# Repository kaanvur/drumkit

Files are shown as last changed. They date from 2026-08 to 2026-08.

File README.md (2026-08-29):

# ESP32-C3 Bluetooth MIDI Drum Kit

> 3D Printer ile basılmış, BLE MIDI ile kablosuz çalışan DIY elektronik davul seti.

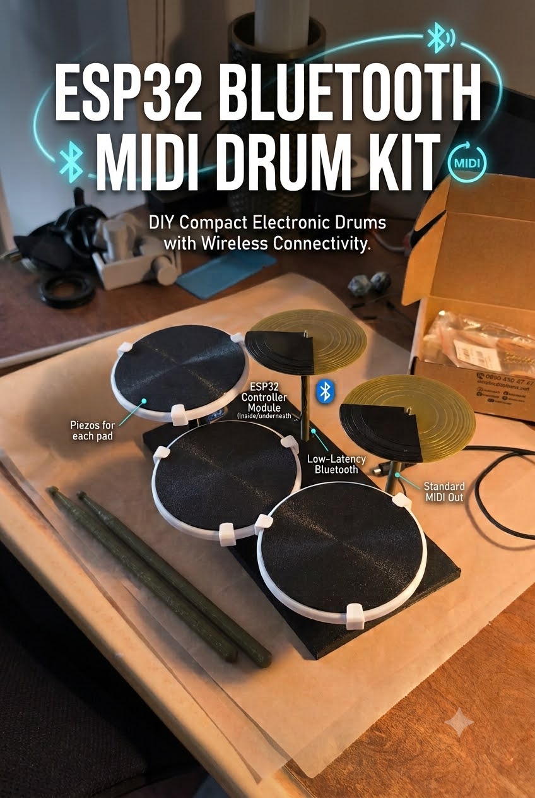
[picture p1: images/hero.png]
Hero


[**MakerWorld'de Görüntüle**](https://makerworld.com/tr/models/3235210-drum-kit-using-esp32-bluetooth-midi)

## 🇹🇷 Türkçe

### Proje Hakkında

Bu proje, **ESP32-C3 Super Mini** mikrodenetleyicisi kullanılarak oluşturulmuş компакт bir elektronik davul setidir. 3D printer ile basılmış pad'ler, piezo sensörler ve Bluetooth Low Energy (BLE) MIDI bağlantısı ile çalışır.

### Ozellikler

- **5 Pad**: Kick, Snare, Hi-Hat, Tom, Crash Cymbal
- **BLE MIDI**: Kablosuz Bluetooth bağlantısı (düşük gecikme)
- **Velocity Sensitivity**: Vuruş şiddetine göre MIDI velocity
- **3D Baskı**: Tamamı 3D printer ile basılabilir gövde
- **Kompakt**: Masaüstü boyutunda, taşınabilir tasarım

### Önemli: Analog Pin Gerekliliği

Piezo sensörler **analog pinlere** bağlanır. Her piezo için bir analog pin gereklidir.

| Mikrodenetleyici | Analog Pin Sayısı | Maks. Pad |
|---|---|---|
| ESP32-C3 Super Mini | 5 (GPIO0-4) | 5 pad |
| ESP32-WROOM-32D | 18 (GPIO32-39, GPIO0-5, GPIO34-39) | 18 pad |
| ESP32-S3 Super Mini | 20 | 20 pad |
| Arduino Uno | 6 (A0-A5) | 6 pad |
| Arduino Nano | 8 (A0-A7) | 8 pad |

> **Daha fazla pad istiyorsanız**: ESP32-WROOM-32D veya ESP32-S3 gibi daha çok analog pin'e sahip kartlar kullanarak 10-15 pad'li更大的鼓组 kurabilirsiniz. Kodda `NUM_PADS` sabitini ve `piezoPins` dizisini değiştirmeniz yeterlidir.

### Gerekli Malzemeler

| Bileşen | Adet | Not |
|---|---|-----|
| ESP32-C3 Super Mini | 1 | USB-C girişli, dahili LED (GPIO8) |
| Piezo Sensör (27mm) | 5 | Her pad için bir adet |
| Direnç (1MΩ) | 5 | Pull-down direnç |
| Jumper Kablo | ~20 | Erkek-dişi |
| USB-C Kablo | 1 | Kod yükleme için |

### 3D Baskı Parçaları

[`drumkit.3mf`](3d-models/drumkit.3mf) dosyası 6 baskı plakası içerir:

| Plaka | Renk | İçerik |
|---|---|---|
| 01 | Beyaz | Pad çerçeveleri + klipsler |
| 02 | Siyah | Pad üst yüzeyleri (3 yuvarlak + 2 zil) |
| 03 | Siyah | Zil ayakları / tutucular |
| 04 | Yeşil | Zil üst yüzeyleri + klipsler |
| 05 | Siyah | Ana gövde (base plate) |
| 06 | Yeşil | Davul çubukları |

**Önerilen malzeme**: PLA veya PLA+ ( PETG de olur )

### Bağlantı Şeması

```
ESP32-C3 Super Mini
┌─────────────────┐
│                 │
│  GPIO0 ──────────── Piezo 1 (Kick)    + 1MΩ direnç
│  GPIO1 ──────────── Piezo 2 (Snare)   + 1MΩ direnç
│  GPIO2 ──────────── Piezo 3 (Hi-Hat)  + 1MΩ direnç
│  GPIO3 ──────────── Piezo 4 (Tom)     + 1MΩ direnç
│  GPIO4 ──────────── Piezo 5 (Cymbal)  + 1MΩ direnç
│                 │
│  GND ────────────── Piezo (-)         │
│                 │
│  USB-C ──────── Kod yükleme           │
└─────────────────┘

Not: GPIO8 - Dahili LED (devreye ekstra LED baglantisi gerekmez)
```

Detaylı bağlantı için: [docs/WIRING.md](docs/WIRING.md)

### Montaj

1. 3D parçaları bas
2. Piezo sensörleri pad'lere yapıştır
3. Kablo lehimleme / bağlama
4. ESP32'yi gövdeye yerleştir
5. Kodu yükle
6. Bluetooth ile bağlan

Detaylı montaj için: [docs/ASSEMBLY.md](docs/ASSEMBLY.md)

### Kod Yükleme

Arduino IDE ile:
1. ESP32 board paketini yükle
2. `firmware/drumkit/drumkit.ino` dosyasını aç
3. Board: "ESP32C3 Dev Module" seç
4. Upload

Detaylı yükleme için: [docs/FLASHING.md](docs/FLASHING.md)

### Bluetooth MIDI Kullanma

Cihaz adı: **ESP32-C3-Drum**

| Platform | Uygulama | Durum |
|---|---|---|
| macOS | GarageBand | ✅ Doğrudan çalışır |
| macOS | Logic Pro | ✅ Doğrudan çalışır |
| iOS | GarageBand | ✅ Doğrudan çalışır |
| iOS | Cubasis 3 | ✅ Doğrudan çalışır |
| Android | n-track Studio | ✅ Doğrudan çalışır |
| Android | Caustic 3 | ✅ Doğrudan çalışır |
| Web | BandLab | ✅ BLE MIDI destekli |
| Web | Soundtrap | ✅ BLE MIDI destekli |
| Windows | loopMIDI + DAW | ⚠️ BLE-MIDI sürücü gerekli |

> **Not**: ESP32-C3 dahili LED (GPIO8) kullanır. Devreye ekstra LED bağlamanıza gerek yoktur.

Detaylı bağlantı ve uygulama kılavuzları için: [docs/BLUETOOTH.md](docs/BLUETOOTH.md)

---

## 🇬🇧 English

### About

A compact DIY electronic drum kit built with an **ESP32-C3 Super Mini** microcontroller. Features 3D-printed pads, piezo sensors, and wireless Bluetooth Low Energy (BLE) MIDI connectivity.

[**View on MakerWorld**](https://makerworld.com/tr/models/3235210-drum-kit-using-esp32-bluetooth-midi)

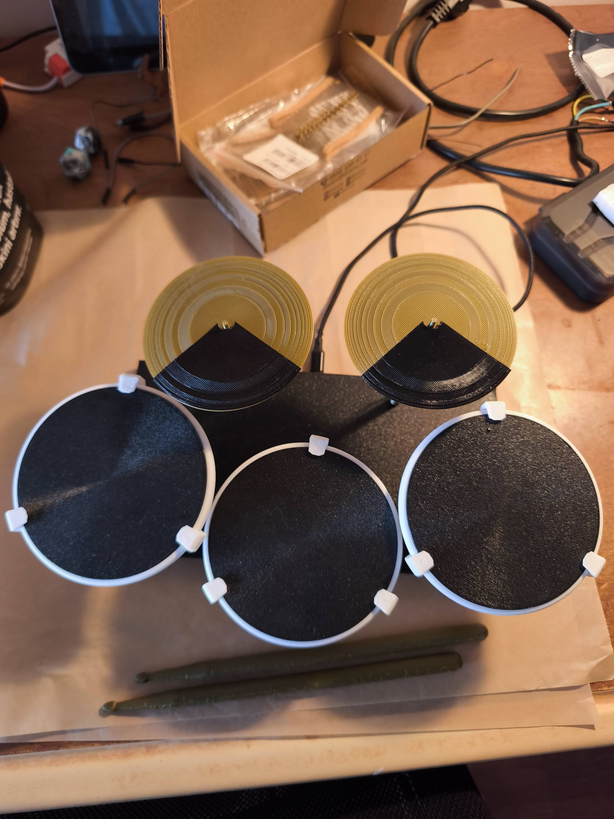
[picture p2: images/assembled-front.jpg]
Assembled


### Features

- **5 Pads**: Kick, Snare, Hi-Hat, Tom, Crash Cymbal
- **BLE MIDI**: Wireless Bluetooth connection (low latency)
- **Velocity Sensitivity**: MIDI velocity based on hit strength
- **3D Printed**: Fully printable body and pads
- **Compact**: Desktop-sized, portable design

### Important: Analog Pin Requirement

Piezo sensors connect to **analog pins**. Each piezo requires one analog pin.

| Microcontroller | Analog Pin Count | Max Pads |
|---|---|---|
| ESP32-C3 Super Mini | 5 (GPIO0-4) | 5 pads |
| ESP32-WROOM-32D | 18 (GPIO32-39, GPIO0-5, GPIO34-39) | 18 pads |
| ESP32-S3 Super Mini | 20 | 20 pads |
| Arduino Uno | 6 (A0-A5) | 6 pads |
| Arduino Nano | 8 (A0-A7) | 8 pads |

> **Need more pads?**: Use microcontrollers with more analog pins like ESP32-WROOM-32D or ESP32-S3 to build larger drum kits with 10-15 pads. Just change the `NUM_PADS` constant and `piezoPins` array in the code.

### Required Components

| Component | Qty | Note |
|---|-----|---|
| ESP32-C3 Super Mini | 1 | USB-C port, built-in LED (GPIO8) |
| Piezo Sensor (27mm) | 5 | One per pad |
| Resistor (1MΩ) | 5 | Pull-down resistor |
| Jumper Wires | ~20 | Male-to-female |
| USB-C Cable | 1 | For flashing |

### 3D Printed Parts

[`drumkit.3mf`](3d-models/drumkit.3mf) contains 6 build plates:

| Plate | Color | Contents |
|---|---|---|
| 01 | White | Pad frames + clips |
| 02 | Black | Pad top surfaces (3 round + 2 cymbal) |
| 03 | Black | Cymbal stands / holders |
| 04 | Green | Cymbal top surfaces + clips |
| 05 | Black | Main base plate |
| 06 | Green | Drumsticks |

**Recommended material**: PLA or PLA+ (PETG works too)

### Wiring Diagram

```
ESP32-C3 Super Mini
┌─────────────────┐
│                 │
│  GPIO0 ──────────── Piezo 1 (Kick)    + 1MΩ resistor
│  GPIO1 ──────────── Piezo 2 (Snare)   + 1MΩ resistor
│  GPIO2 ──────────── Piezo 3 (Hi-Hat)  + 1MΩ resistor
│  GPIO3 ──────────── Piezo 4 (Tom)     + 1MΩ resistor
│  GPIO4 ──────────── Piezo 5 (Cymbal)  + 1MΩ resistor
│                 │
│  GND ────────────── Piezo (-)         │
│                 │
│  USB-C ──────── Flashing              │
└─────────────────┘

Note: GPIO8 - Built-in LED (no external LED connection needed)
```

For detailed wiring: [docs/WIRING.md](docs/WIRING.md)

### Assembly

1. 3D print all parts
2. Attach piezo sensors to pads
3. Solder / connect wires
4. Mount ESP32 into base
5. Flash the firmware
6. Connect via Bluetooth

For detailed assembly: [docs/ASSEMBLY.md](docs/ASSEMBLY.md)

### Flashing

Using Arduino IDE:
1. Install ESP32 board package
2. Open `firmware/drumkit/drumkit.ino`
3. Select board: "ESP32C3 Dev Module"
4. Upload

For detailed instructions: [docs/FLASHING.md](docs/FLASHING.md)

### Using Bluetooth MIDI

Device name: **ESP32-C3-Drum**

| Platform | App | Status |
|---|-----|---|
| macOS | GarageBand | ✅ Works out of the box |
| macOS | Logic Pro | ✅ Works out of the box |
| iOS | GarageBand | ✅ Works out of the box |
| iOS | Cubasis 3 | ✅ Works out of the box |
| Android | n-track Studio | ✅ Works out of the box |
| Android | Caustic 3 | ✅ Works out of the box |
| Web | BandLab | ✅ BLE MIDI supported |
| Web | Soundtrap | ✅ BLE MIDI supported |
| Windows | loopMIDI + DAW | ⚠️ BLE-MIDI driver needed |

> **Note**: ESP32-C3 uses built-in LED (GPIO8). No external LED connection needed.

For detailed connection and app guides: [docs/BLUETOOTH.md](docs/BLUETOOTH.md)

---

## 📁 Project Structure / Proje Yapısı

```
drumkit/
├── README.md              # This file / Bu dosya
├── LICENSE                # CC BY-NC-SA 4.0
├── firmware/
│   └── drumkit/
│       └── drumkit.ino    # Arduino code / Arduino kodu
├── 3d-models/
│   └── drumkit.3mf        # 3D print file / 3D baskı dosyası
├── docs/
│   ├── WIRING.md          # Wiring guide / Bağlantı rehberi
│   ├── ASSEMBLY.md        # Assembly guide / Montaj rehberi
│   ├── FLASHING.md        # Flashing guide / Kod yükleme rehberi
│   └── BLUETOOTH.md       # Bluetooth MIDI guide / Bluetooth rehberi
└── images/                # Documentation images / Görseller
```

## 📜 License / Lisans

**CC BY-NC-SA 4.0** (Creative Commons Atıf-GayriTicari-AyniLisanslaPaylaş 4.0 Uluslararası)

Bu eser:
- ✅ Kişisel/bireysel kullanım için özgürdür
- ✅ Atıf ile alıntı yapabilirsiniz
- ✅ Değiştirip türetebilirsiniz
- ✗ Ticari amaçla kullanılamaz
- ⚠️ Türev eserler aynı lisansla (CC BY-NC-SA 4.0) paylaşılmalıdır

Detaylı lisans için: [LICENSE](LICENSE)

## � Katkıda Bulunma

Hata bildirimi veya geliştirme önerileriniz için Issue açabilirsiniz.

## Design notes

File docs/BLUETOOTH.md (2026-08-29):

# Bluetooth MIDI Bağlantı Rehberi / Bluetooth MIDI Connection Guide

## 🇹🇷 Türkçe

### Genel Bakış

ESP32-C3 drum kit'iniz **BLE MIDI** (Bluetooth Low Energy MIDI) protokolü ile çalışır. Bu, iOS, macOS ve Android cihazlarla kablosuz olarak MIDI sinyali gönderebilmenizi sağlar.

Cihaz adı: **ESP32-C3-Drum**

> İlk açılışta veya bağlantı koptuğunda ESP32-C3 otomatik olarak reklam (advertising) yapmaya başlar.

---

### macOS (MacBook / iMac) Bağlantısı

#### Adım 1: Bluetooth'u Açın

1. **Sistem Ayarları** (System Settings) > **Bluetooth** menüsüne gidin
2. Bluetooth'u **Açık** konuma getirin
3. "ESP32-C3-Drum" cihazını arama listesinde görün

> Eğer cihaz görünüyorsa, cihaz zaten reklam modundadır. Görünmüyorsa ESP32-C3'ü USB ile besleyin veya RESET butonuna basın.

#### Adım 2: Cihaza Bağlanın

1. "ESP32-C3-Drum" yanındaki **"Bağlan"** (Connect) butonuna tıklayın
2. Bağlantı kurulana kadar bekleyin
3. Bağlantı başarılı olduğunda "Bağlı" (Connected) yazacak

```
Bluetooth Ayarları:
┌─────────────────────────────────────────┐
│  Bulunan Cihazlar:                       │
│                                         │
│  🎵 ESP32-C3-Drum          [Bağlan]     │
│                                         │
└─────────────────────────────────────────┘
```

#### Adım 3: MIDI Studio'da Doğrulama

1. **Araçlar** (Applications) > **Utilites** (Utilities) > **Audio MIDI Kurulumu** (Audio MIDI Setup) uygulamasını açın
2. Üst menüden **Pencere** (Window) > **MIDI Stüdyo** (MIDI Studio) seçin
3. MIDI Studio penceresinde **"ESP32-C3-Drum"** cihazını görmelisiniz
4. Cihaza çift tıklayarak MIDI portlarının aktif olduğunu doğrulayın

> Bu adım zorunlu değildir, ancak bağlantının doğru kurulduğunu doğrulamak için faydalıdır.

#### Adım 4: GarageBand'de Kullanma

1. **GarageBand**'ı açın
2. Yeni bir proje oluşturun veya mevcut bir projeyi açın
3. **Yeni Parça** (New Track) > **Yazılı Enstrüman** (Software Instrument) seçin
4. Sol panelde **Klavye** (Keyboard) veya **Davul Seti** (Drum Kit) enstrümanını seçin

##### MIDI Bağlantısını Ayarlama

1. GarageBand menü çubuğunda **GarageBand > Tercihler** (Preferences) seçin
2. **MIDI** sekmesine gidin
3. **MIDI Giriş** (MIDI Input) bölümünde **"ESP32-C3-Drum"** seçin

```
GarageBand Tercihler:
┌─────────────────────────────────────────┐
│  MIDI                                    │
│                                         │
│  MIDI Giriş: [ ESP32-C3-Drum ▼]         │
│                                         │
│  ✅ MIDI saatini başlat                  │
│  ✅ Sampringleme hızı: 44.1 kHz          │
└─────────────────────────────────────────┘
```

##### Davul Enstrümanı Seçme

GarageBand'de davul sesi almak için:

1. Yeni bir **Yazılı Enstrüman** parçası ekleyin
2. Sol panelde **"Davul Seti"** (Drum Kit) kategorisine gidin
3. İstediğiniz davul preset'ini seçin (örn: "Classic Studio Kit", "Electronic Kit")
4. Pad'lerinize vurun - ses gelmeli

> **İpucu**: GarageBand'de "Drum Machine" veya "Electronic Drum Kit" preset'leri MIDI velocity'yi daha iyi algılar.

##### MIDI凱rtlama (MIDI Mapping)

GarageBand otomatik olarak General MIDI drum haritalamasını kullanır:

| Pad | MIDI Notu | GarageBand'de |
|-----|---|---|
| Kick | C1 (36) | Bass Drum |
| Snare | D1 (38) | Snare Drum |
| Hi-Hat | F#1 (42) | Closed Hi-Hat |
| Tom | C2 (48) | Mid Tom |
| Cymbal | C#2 (49) | Crash Cymbal |

##### Sorun Giderme

**Ses gelmiyor:**
- GarageBand'de MIDI girişinin doğru seçildiğinden emin olun
- Pad'lerinize vurduğunuzda Serial Monitor'de "Velocity" değerleri görünmeli
- GarageBand'de parçanın **Sessiz** (Mute) veya **Solo** durumda olmadığından emin olun

**Gecikme var:**
- BLE MIDI düşük gecikmelidir (~10ms), ancak macOS Bluetooth yığınına bağlıdır
- Diğer Bluetooth cihazlarını kapatmayı deneyin
- USB MIDI kullanmak isterseniz, ESP32-C3 USB-MID desteğini araştırın

**Bağlantı kopuyor:**
- ESP32-C3 menzilinin 5-10 metre olduğunu unutmayın
- Fiziksel engeller (duvar, metal) bağlantıyı zayıflatabilir
- Batarya seviyesi düşükse cihazı beslemeyi kontrol edin

---

### Android Bağlantısı

#### Genel Bakış

Android'de BLE MIDI, **Android 6.0 (API 23)** ve üzeri sürümlerde desteklenir. Google'ın **BLE MIDI** özelliği Android 6.0'dan itibaren işletim sistemine entegre edilmiştir.

#### Adım 1: Bluetooth'u Açın

1. **Ayarlar** > **Bağlantılar** > **Bluetooth**
2. Bluetooth'u **Açık** konuma getirin

#### Adım 2: Cihaza Bağlanma

**Önemli**: Android'de BLE MIDI cihazları normal Bluetooth cihazları gibi "Eşleştirilmez". Uygulama içinden bağlanılır.

1. Kullanacağınız MIDI uygulamasını açın (örn: n-track Studio)
2. Uygulama içinde BLE MIDI taraması başlatın
3. "ESP32-C3-Drum" cihazını seçin
4. Bağlantı kurulana kadar bekleyin

> Eğer cihaz Bluetooth ayarlarında görünüyorsa bile, uygulama içinden bağlanmanız gerekir.

#### n-track Studio ile Kullanım

**n-track Studio**, Android'de ücretsiz olarak kullanılabilecek güçlü bir DAW uygulamasıdır.

##### Kurulum

1. Google Play Store'dan **n-track Studio**'yu indirin
2. Uygulamayı açın
3. İlk açılışta gerekli izinleri verin

##### BLE MIDI Bağlantısı

1. n-track Studio'da **Ayarlar** (Settings) > **MIDI** bölümüne gidin
2. **BLE MIDI Cihazları** (BLE MIDI Devices) seçeneğine dokunun
3. Tarama başlatın
4. **"ESP32-C3-Drum"** cihazını seçin
5. Bağlantı başarılı olduğunda yeşil işaret görünecek

```
n-track Studio - MIDI Ayarları:
┌─────────────────────────────────────────┐
│  MIDI Ayarları                           │
│                                         │
│  BLE MIDI Cihazları:                     │
│  ┌─────────────────────────────────┐    │
│  │ ✅ ESP32-C3-Drum    [Bağlı]     │    │
│  └─────────────────────────────────┘    │
│                                         │
│  MIDI Giriş: ESP32-C3-Drum              │
│  MIDI Kanal: 10 (Drum)                  │
└─────────────────────────────────────────┘
```

##### Davul Seti Yükleme

1. Yeni bir **Davul Parçası** (Drum Track) ekleyin
2. **Enstrüman Seç** (Choose Instrument) > **Davul Seti** (Drum Kit) seçin
3. İstediğiniz davul preset'ini seçin
4. Pad'lerinize vurun

##### MIDI Haritalama

n-track Studio General MIDI drum haritalamasını kullanır:

| Pad | MIDI Notu | n-track Studio'da |
|-----|---|---|
| Kick | C1 (36) | Bass Drum |
| Snare | D1 (38) | Snare |
| Hi-Hat | F#1 (42) | Closed Hi-Hat |
| Tom | C2 (48) | Tom |
| Cymbal | C#2 (49) | Crash |

##### Kayıt Yapma

1. **Kayıt** (Record) butonuna basın
2. Tempo ayarlayın (BPM)
3. Pad'lerinize vurarak davul loop'u kaydedin
4. Kaydı durdurun ve düzenleyin

##### İpuçları

- **Latency**: n-track Studio'da gecikme ayarını **Audio Setup** > **Buffer Size** bölümünden düşürebilirsiniz (128 veya 256 samples önerilir)
- **Velocity**: Pad'lerinize farklı şiddette vurarak dynamic davul kayıtları yapabilirsiniz
- **Quantize**: Kayıt sonrası "Quantize" özelliği ile vuruşları hizalayabilirsiniz

#### Diğer Android Uygulamaları

| Uygulama | Özellik | Ücretsiz |
|---|---|---|
| **n-track Studio** | Tam DAW, kayıt, düzenleme | ✅ (Temel) |
| **USB MIDI Player** | MIDI dosyalarını çalma | ✅ |
| **MIDI Connector** | BLE MIDI → USB MIDI dönüştürücü | ✅ |
| **Caustic 3** | Synth ve drum machine | ✅ (Tam) |
| **Groovebox** | Beat maker | ✅ (Sınırlı) |

---

### iOS (iPhone / iPad) Bağlantısı

> iOS, BLE MIDI'yi doğrudan destekler.

1. **Ayarlar** > **Bluetooth**
2. Bluetooth'u açın
3. Kullanacağınız uygulamada "ESP32-C3-Drum" seçin

**Önerilen uygulamalar:**
- **GarageBand** (Ücretsiz)
- **Cubasis 3** (Profesyonel DAW)
- **AUM** (Mixer/Router)
- **MIDI Wrench** (MIDI test aracı)

---

### Çevrimiçi Platformlar (Platform Bağımsız)

ESP32-C3 drum kit'iniz sadece yerel uygulamalarla değil, aynı zamanda **çevrimiçi DAW** platformlarıyla da çalışır. Bu sayede herhangi bir uygulama indirmenize gerek kalmadan tarayıcı üzerinden müzik yapabilirsiniz.

#### BandLab (bandlab.com)

BandLab, ücretsiz çevrimiçi DAW'dır. BLE MIDI cihazlarını doğrudan destekler.

##### Bağlantı Adımları

1. **Telefonunuzdan** BandLab uygulamasını veya tarayıcınızdan **bandlab.com** adresini açın
2. Yeni bir proje oluşturun veya mevcut bir projeyi açın
3. **Bluetooth MIDI Bağlantısı**:
   - **Android**: Uygulama içinden BLE MIDI taraması başlatın → "ESP32-C3-Drum" seçin
   - **iOS**: Uygulama BLE MIDI'yi otomatik algılar → "ESP32-C3-Drum" seçin
4. Yeni bir **Davul** (Drum) parçası ekleyin
5. Pad'lerinize vurarak test edin

```
BandLab - Davul Parçası Oluşturma:
┌─────────────────────────────────────────┐
│  + Track > Drum > Empty Kit             │
│                                         │
│  MIDI Input: ESP32-C3-Drum              │
│  Channel: 10                            │
└─────────────────────────────────────────┘
```

##### BandLab İpuçları

- **Davul Preset'leri**: "808 Kit", "Acoustic Kit", "Electronic Kit" gibi preset'leri deneyin
- **Loop Kayıt**: Bir loop kaydedin, sonra其他的 parçaları ekleyin
- **Paylaşım**: Kaydettiğiniz projeleri doğrudan BandLab'de paylaşabilirsiniz

#### Soundtrap (soundtrap.com)

Soundtrap (Spotify'ın online DAW'ı) da BLE MIDI destekler.

1. **soundtrap.com** adresine gidin
2. Yeni proje oluşturun
3. **MIDIForKeyboard** ayarlarında "ESP32-C3-Drum" seçin
4. Davul parçası ekleyin ve çalmaya başlayın

#### CodePen / Web MIDI API

Geliştiriciler için: Web MIDI API ile tarayıcıda doğrudan MIDI alabilirsiniz.

```javascript
// Web MIDI API ile ESP32-C3 drum kit'i okuma
navigator.requestMIDIAccess().then(midiAccess => {
  for (const input of midiAccess.inputs.values()) {
    input.onmidimessage = (event) => {
      const [status, note, velocity] = event.data;
      console.log(`Pad: ${note}, Velocity: ${velocity}`);
    };
  }
});
```

> Bu özellik sadece Chrome ve Edge tarayıcılarında çalışır. Safari'de sınırlı destek vardır.

#### Diğer Çevrimiçi Platformlar

| Platform | URL | MIDI Desteği | Not |
|---|-----|---|-----|
| **BandLab** | bandlab.com | ✅ BLE MIDI | Ücretsiz, mobil + web |
| **Soundtrap** | soundtrap.com | ✅ BLE MIDI | Spotify DAW, ücretli |
| **Amped Studio** | ampedstudio.com | ✅ Web MIDI | Ücretsiz deneme |
| **AudioTool** | audiotool.com | ⚠️ Sadece USB | Android için uygun değil |
| **Soundation** | soundation.com | ⚠️ Sınırlı | Ücretsiz plan mevcut |

> **Not**: Çevrimiçi platformlarda BLE MIDI desteği cihazın işletim sistemine bağlıdır. macOS ve iOS'ta doğrudan çalışır. Android'de uygulama içi BLE MIDI bağlantısı gerekir.

---

### Genel Sorun Giderme

#### Bağlantı Kurulamıyor

1. **ESP32-C3'ün açık olduğundan emin olun**: USB-C ile beslenmeli veya pilli olmalı
2. **Reklam modu**: Bağlantı koptuğunda ESP32 otomatik olarak tekrar reklam yapar. RESET butonuna basarak manuel olarak yeniden başlatın
3. **Menzil**: 5-10 metre menzil içeriside olun
4. **Engeller**: Duvarlar ve metal yüzeyler BLE sinyalini zayıflatabilir
5. **Başka cihazlar**: Önceki Bluetooth MIDI bağlantılarını kesin

#### Ses Gelmiyor

1. **MIDI kanalı**: Drum sesleri genellikle **MIDI Kanal 10**'da çalışır. Kodda bu ayar doğru (Channel 10 / 0x99)
2. **Velocity**: Çok hafif vuruşlar algılanmayabilir. Orta şiddette vurmayı deneyin
3. **MIDI notaları**: Kullandığınız uygulamanın General MIDI drum haritalamasını desteklediğinden emin olun

#### Gecikme (Latency) Sorunu

- BLE MIDI natif olarak ~10ms gecikmeye sahiptir
- macOS/iOS'ta bu genellikle sorun oluşturmaz
- Android'de bazı cihazlarda 20-30ms'ye kadar çıkabilir
- Düşük gecikme için:
  - Başka Bluetooth cihazlarını kapatın
  - Uygulama içinde buffer size'ı düşürün
  - WiFi bağlantısını devre dışı bırakın (2.4GHz çakışma)

---

## 🇬🇧 English

### Overview

Your ESP32-C3 drum kit uses **BLE MIDI** (Bluetooth Low Energy MIDI) protocol. This allows wireless MIDI signal transmission to iOS, macOS, and Android devices.

Device name: **ESP32-C3-Drum**

> On first boot or after disconnection, ESP32-C3 automatically starts advertising.

---

### macOS (MacBook / iMac) Connection

#### Step 1: Enable Bluetooth

1. Open **System Settings** > **Bluetooth**
2. Turn Bluetooth **On**
3. Look for "ESP32-C3-Drum" in the device list

> If the device appears, it's already in advertising mode. If not, power the ESP32-C3 via USB or press RESET.

#### Step 2: Connect

1. Click **"Connect"** next to "ESP32-C3-Drum"
2. Wait for connection to establish
3. Status will change to "Connected"

```
Bluetooth Settings:
┌─────────────────────────────────────────┐
│  Nearby Devices:                         │
│                                         │
│  🎵 ESP32-C3-Drum          [Connect]    │
│                                         │
└─────────────────────────────────────────┘
```

#### Step 3: Verify in MIDI Studio

1. Open **Applications** > **Utilities** > **Audio MIDI Setup**
2. Go to **Window** > **MIDI Studio**
3. You should see **"ESP32-C3-Drum"** in the MIDI Studio window
4. Double-click the device to verify MIDI ports are active

> This step is optional but useful for verifying correct connection.

#### Step 4: Use in GarageBand

1. Open **GarageBand**
2. Create a new project or open existing one
3. **New Track** > **Software Instrument**
4. Select **Keyboard** or **Drum Kit** instrument from the left panel

##### MIDI Configuration

1. In GarageBand menu bar, go to **GarageBand > Preferences**
2. Click the **MIDI** tab
3. Under **MIDI Input**, select **"ESP32-C3-Drum"**

```
GarageBand Preferences:
┌─────────────────────────────────────────┐
│  MIDI                                    │
│                                         │
│  MIDI Input: [ ESP32-C3-Drum ▼]         │
│                                         │
│  ✅ Enable MIDI clock                    │
│  ✅ Sampling rate: 44.1 kHz              │
└─────────────────────────────────────────┘
```

##### Selecting Drum Instrument

1. Add a new **Software Instrument** track
2. In the left panel, go to **"Drum Kit"** category
3. Choose a drum preset (e.g., "Classic Studio Kit", "Electronic Kit")
4. Hit your pads - you should hear sound

> **Tip**: "Drum Machine" or "Electronic Drum Kit" presets in GarageBand respond better to MIDI velocity.

##### MIDI Mapping

GarageBand uses General MIDI drum mapping by default:

| Pad | MIDI Note | In GarageBand |
|-----|---|---|
| Kick | C1 (36) | Bass Drum |
| Snare | D1 (38) | Snare Drum |
| Hi-Hat | F#1 (42) | Closed Hi-Hat |
| Tom | C2 (48) | Mid Tom |
| Cymbal | C#2 (49) | Crash Cymbal |

##### Troubleshooting

**No sound:**
- Verify MIDI input is correctly selected in GarageBand preferences
- Serial Monitor should show "Velocity" values when hitting pads
- Make sure track is not Muted or in Solo mode

**Latency:**
- BLE MIDI has low latency (~10ms), but depends on macOS Bluetooth stack
- Try turning off other Bluetooth devices
- For USB MIDI, look into ESP32-C3 USB-MIDI support

**Connection drops:**
- BLE range is 5-10 meters
- Physical obstacles (walls, metal) can weaken signal
- Check power supply if running on battery

---

### Android Connection

#### Overview

On Android, BLE MIDI is supported from **Android 6.0 (API 23)** and above. Google integrated BLE MIDI into the OS starting from Android 6.0.

#### Step 1: Enable Bluetooth

1. **Settings** > **Connections** > **Bluetooth**
2. Turn Bluetooth **On**

#### Step 2: Connecting

**Important**: On Android, BLE MIDI devices don't pair like regular Bluetooth devices. Connection happens within the app.

1. Open your MIDI app (e.g., n-track Studio)
2. Start BLE MIDI scan within the app
3. Select "ESP32-C3-Drum"
4. Wait for connection

> Even if the device appears in Bluetooth settings, you must connect through the app.

#### Using n-track Studio

**n-track Studio** is a powerful free DAW app for Android.

##### Setup

1. Download **n-track Studio** from Google Play Store
2. Open the app
3. Grant required permissions on first launch

##### BLE MIDI Connection

1. In n-track Studio, go to **Settings** > **MIDI**
2. Tap **BLE MIDI Devices**
3. Start scan
4. Select **"ESP32-C3-Drum"**
5. Green indicator shows successful connection

```
n-track Studio - MIDI Settings:
┌─────────────────────────────────────────┐
│  MIDI Settings                           │
│                                         │
│  BLE MIDI Devices:                       │
│  ┌─────────────────────────────────┐    │
│  │ ✅ ESP32-C3-Drum    [Connected] │    │
│  └─────────────────────────────────┘    │
│                                         │
│  MIDI Input: ESP32-C3-Drum              │
│  MIDI Channel: 10 (Drum)                │
└─────────────────────────────────────────┘
```

##### Loading Drum Kit

1. Add a new **Drum Track**
2. **Choose Instrument** > **Drum Kit**
3. Select desired drum preset
4. Hit your pads

##### MIDI Mapping

n-track Studio uses General MIDI drum mapping:

| Pad | MIDI Note | In n-track Studio |
|-----|---|---|
| Kick | C1 (36) | Bass Drum |
| Snare | D1 (38) | Snare |
| Hi-Hat | F#1 (42) | Closed Hi-Hat |
| Tom | C2 (48) | Tom |
| Cymbal | C#2 (49) | Crash |

##### Recording

1. Press **Record** button
2. Set tempo (BPM)
3. Hit pads to record drum loop
4. Stop recording and edit

##### Tips

- **Latency**: Reduce latency in **Audio Setup** > **Buffer Size** (128 or 256 samples recommended)
- **Velocity**: Hit pads with different force for dynamic drum recordings
- **Quantize**: Use "Quantize" feature after recording to align hits

#### Other Android Apps

| App | Features | Free |
|-----|---|---|
| **n-track Studio** | Full DAW, recording, editing | ✅ (Basic) |
| **USB MIDI Player** | Play MIDI files | ✅ |
| **MIDI Connector** | BLE MIDI → USB MIDI converter | ✅ |
| **Caustic 3** | Synth and drum machine | ✅ (Full) |
| **Groovebox** | Beat maker | ✅ (Limited) |

---

### iOS (iPhone / iPad) Connection

> iOS natively supports BLE MIDI.

1. **Settings** > **Bluetooth**
2. Turn Bluetooth on
3. Select "ESP32-C3-Drum" in your app

**Recommended apps:**
- **GarageBand** (Free)
- **Cubasis 3** (Professional DAW)
- **AUM** (Mixer/Router)
- **MIDI Wrench** (MIDI testing tool)

---

### Online Platforms (Platform Independent)

Your ESP32-C3 drum kit works not only with local apps but also with **online DAW** platforms. This allows you to make music directly in your browser without installing any applications.

#### BandLab (bandlab.com)

BandLab is a free online DAW that natively supports BLE MIDI devices.

##### Connection Steps

1. Open the **BandLab app** on your phone or go to **bandlab.com** in your browser
2. Create a new project or open an existing one
3. **BLE MIDI Connection**:
   - **Android**: Start BLE MIDI scan within the app → Select "ESP32-C3-Drum"
   - **iOS**: App auto-detects BLE MIDI → Select "ESP32-C3-Drum"
4. Add a new **Drum** track
5. Test by hitting your pads

```
BandLab - Creating Drum Track:
┌─────────────────────────────────────────┐
│  + Track > Drum > Empty Kit             │
│                                         │
│  MIDI Input: ESP32-C3-Drum              │
│  Channel: 10                            │
└─────────────────────────────────────────┘
```

##### BandLab Tips

- **Drum Presets**: Try "808 Kit", "Acoustic Kit", "Electronic Kit" presets
- **Loop Recording**: Record a loop, then add other tracks
- **Sharing**: Share your projects directly on BandLab

#### Soundtrap (soundtrap.com)

Soundtrap (Spotify's online DAW) also supports BLE MIDI.

1. Go to **soundtrap.com**
2. Create a new project
3. Select "ESP32-C3-Drum" in MIDI keyboard settings
4. Add a drum track and start playing

#### CodePen / Web MIDI API

For developers: You can read MIDI directly in the browser using the Web MIDI API.

```javascript
// Reading ESP32-C3 drum kit with Web MIDI API
navigator.requestMIDIAccess().then(midiAccess => {
  for (const input of midiAccess.inputs.values()) {
    input.onmidimessage = (event) => {
      const [status, note, velocity] = event.data;
      console.log(`Pad: ${note}, Velocity: ${velocity}`);
    };
  }
});
```

> This feature works only in Chrome and Edge browsers. Safari has limited support.

#### Other Online Platforms

| Platform | URL | MIDI Support | Note |
|---|-----|---|---|
| **BandLab** | bandlab.com | ✅ BLE MIDI | Free, mobile + web |
| **Soundtrap** | soundtrap.com | ✅ BLE MIDI | Spotify DAW, paid |
| **Amped Studio** | ampedstudio.com | ✅ Web MIDI | Free trial |
| **AudioTool** | audiotool.com | ⚠️ USB only | Not suitable for Android |
| **Soundation** | soundation.com | ⚠️ Limited | Free plan available |

> **Note**: BLE MIDI support on online platforms depends on the device's operating system. Works directly on macOS and iOS. On Android, in-app BLE MIDI connection is required.

---

### General Troubleshooting

#### Cannot Connect

1. **Ensure ESP32-C3 is powered**: Via USB-C or battery
2. **Advertising mode**: After disconnection, ESP32 re-advertises automatically. Press RESET to restart manually
3. **Range**: Stay within 5-10 meters
4. **Obstacles**: Walls and metal surfaces weaken BLE signal
5. **Other devices**: Disconnect previous Bluetooth MIDI connections

#### No Sound

1. **MIDI channel**: Drums typically use **MIDI Channel 10**. Code is configured correctly (Channel 10 / 0x99)
2. **Velocity**: Very light hits may not be detected. Try medium force
3. **MIDI notes**: Ensure your app supports General MIDI drum mapping

#### Latency Issues

- BLE MIDI has ~10ms native latency
- On macOS/iOS this is usually not an issue
- On Android, some devices may show 20-30ms
- For low latency:
  - Turn off other Bluetooth devices
  - Reduce buffer size in app settings
  - Disable WiFi (2.4GHz interference)

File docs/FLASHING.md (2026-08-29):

# Kod Yükleme Rehberi / Flashing Guide

## 🇹🇷 Türkçe

### Ön Gereksinimler

1. **Arduino IDE** (v2.x önerilir): https://www.arduino.cc/en/software
2. **ESP32 Board Paketi**

### ESP32 Board Paketini Yükleme

1. Arduino IDE'i açın
2. `Dosya > Tercihler` (File > Preferences) menüsüne gidin
3. "Additional Boards Manager URLs" alanına şunu ekleyin:
   ```
   https://espressif.github.io/arduino-esp32/package_esp32_index.json
   ```
4. `Tamam` (OK) butonuna tıklayın
5. `Araçlar > Panolar > Panolar Yöneticisi` (Tools > Board > Boards Manager)gidin
6. "esp32" arayın
7. **"esp32 by Espressif Systems"** paketini yükleyin

### Board Seçimi

1. `Araçlar > Panolar` (Tools > Board) menüsüne gidin
2. **"ESP32C3 Dev Module"** seçin

Diğer ayarlar (varsayılan olabilir):
- Upload Speed: 921600
- Flash Frequency: 80MHz
- Flash Mode: QIO
- Flash Size: 4MB
- Partition Scheme: Default 4MB with spiffs

### Kodu Yükleme

1. `firmware/drumkit/drumkit.ino` dosyasını Arduino IDE'de açın
2. USB-C kablo ile ESP32-C3'ü bilgisayara bağlayın
3. `Araçlar > Port` menüsünden doğru portu seçin
   - macOS: `/dev/cu.usbmodem*` veya `/dev/cu.usbserial*`
   - Windows: `COM*`
   - Linux: `/dev/ttyACM*` veya `/dev/ttyUSB*`
4. **Upload** (Yükle) butonuna tıklayın

### Yükleme Sırasında Sorun Yaşarsanız

**ESP32 modu algılanmıyor:**
- ESP32-C3 Super Mini'de **BOOT** butonuna basılı tutun
- Upload butonuna tıklayın
- Yazma başladığında butonu bırakın

**Port görünmüyor:**
- USB-C kablosunun veri aktarımı desteklediğinden emin olun
- Farklı bir kablo deneyin
- USB sürücüsünü kontrol edin

**Hata: "Failed to connect"**
- BOOT butonunu basılı tutarak deneyin
- Serialmonitore bağlanıp 115200 baud'de hata mesajını kontrol edin

### BLE MIDI Kullanma

1. Kod yüklendikten sonra ESP32-C3 otomatik olarak reklam yapmaya başlar
2. Telefonunuzda / bilgisayarınızda Bluetooth'u açın
3. **"ESP32-C3-Drum"** cihazını arayın ve bağlanın
4. MIDI uygulamasında bu cihazı seçin (GarageBand, y MIDI Connector, etc.)

### Seri Monitör (Debug)

Kod yüklendikten sonra Serial Monitor'de şu bilgileri görebilirsiniz:
```
================================
ESP32-C3 5 PAD DRUM HAZIR
GPIO2 TERS TRIGGER MODUNDA
================================
KICK | ADC: 1200 | Trigger: 1200 | Peak: 1800 | Velocity: 85
SNARE | ADC: 800 | Trigger: 800 | Peak: 1400 | Velocity: 72
```

Baud hızı: **115200**

---

## 🇬🇧 English

### Prerequisites

1. **Arduino IDE** (v2.x recommended): https://www.arduino.cc/en/software
2. **ESP32 Board Package**

### Installing ESP32 Board Package

1. Open Arduino IDE
2. Go to `File > Preferences`
3. In "Additional Boards Manager URLs", add:
   ```
   https://espressif.github.io/arduino-esp32/package_esp32_index.json
   ```
4. Click OK
5. Go to `Tools > Board > Boards Manager`
6. Search for "esp32"
7. Install **"esp32 by Espressif Systems"**

### Board Selection

1. Go to `Tools > Board`
2. Select **"ESP32C3 Dev Module"**

Other settings (should be defaults):
- Upload Speed: 921600
- Flash Frequency: 80MHz
- Flash Mode: QIO
- Flash Size: 4MB
- Partition Scheme: Default 4MB with spiffs

### Flashing

1. Open `firmware/drumkit/drumkit.ino` in Arduino IDE
2. Connect ESP32-C3 via USB-C cable
3. Select correct port in `Tools > Port`
   - macOS: `/dev/cu.usbmodem*` or `/dev/cu.usbserial*`
   - Windows: `COM*`
   - Linux: `/dev/ttyACM*` or `/dev/ttyUSB*`
4. Click **Upload**

### Troubleshooting

**ESP32 not detected:**
- Hold the **BOOT** button on ESP32-C3 Super Mini
- Click Upload
- Release button when writing starts

**Port not showing:**
- Make sure USB-C cable supports data transfer
- Try a different cable
- Check USB drivers

**Error: "Failed to connect"**
- Try holding BOOT button
- Connect to Serial Monitor at 115200 baud to check error messages

### Using BLE MIDI

1. After flashing, ESP32-C3 starts advertising automatically
2. Enable Bluetooth on your phone / computer
3. Look for **"ESP32-C3-Drum"** device and connect
4. Select this device in your MIDI app (GarageBand, MIDI Connector, etc.)

### Serial Monitor (Debug)

After flashing, you can see these in Serial Monitor:
```
================================
ESP32-C3 5 PAD DRUM HAZIR
GPIO2 TERS TRIGGER MODUNDA
================================
KICK | ADC: 1200 | Trigger: 1200 | Peak: 1800 | Velocity: 85
SNARE | ADC: 800 | Trigger: 800 | Peak: 1400 | Velocity: 72
```

Baud rate: **115200**

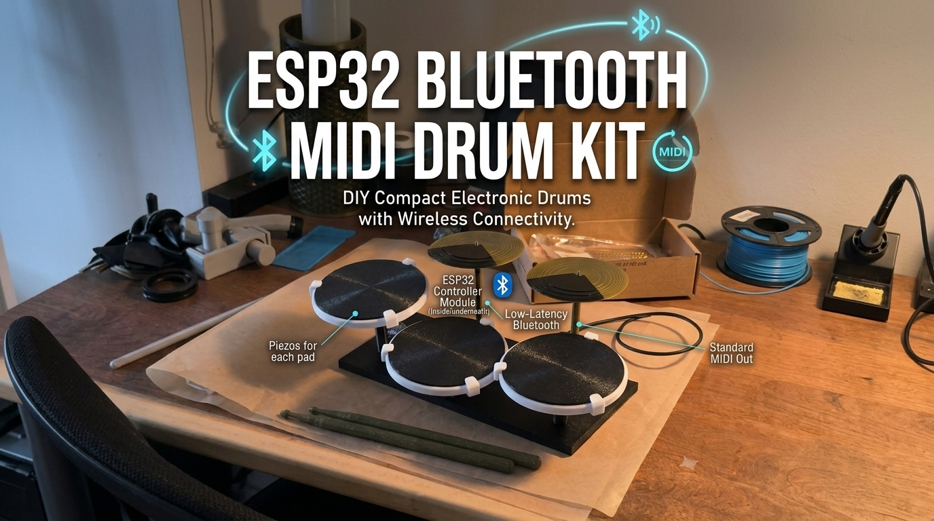
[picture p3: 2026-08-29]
images/hero-landscape.jpeg

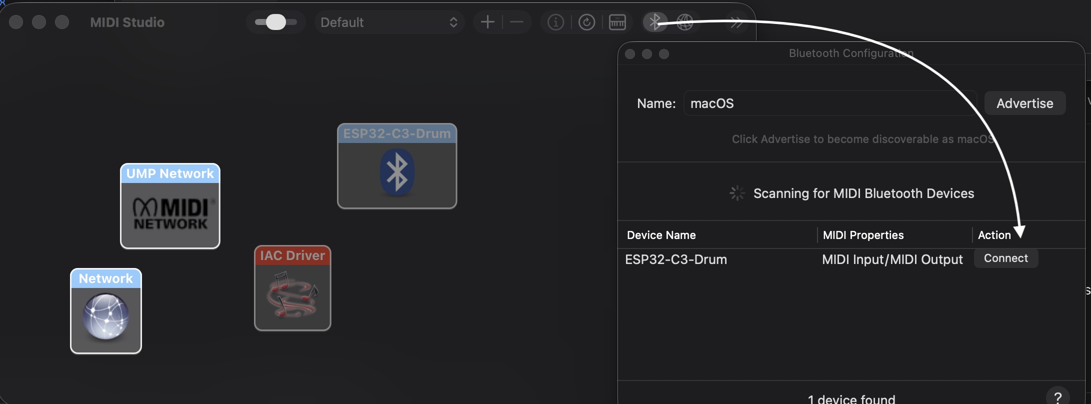
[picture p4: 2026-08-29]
images/macbook_midi_bluetooth_connetion.jpg

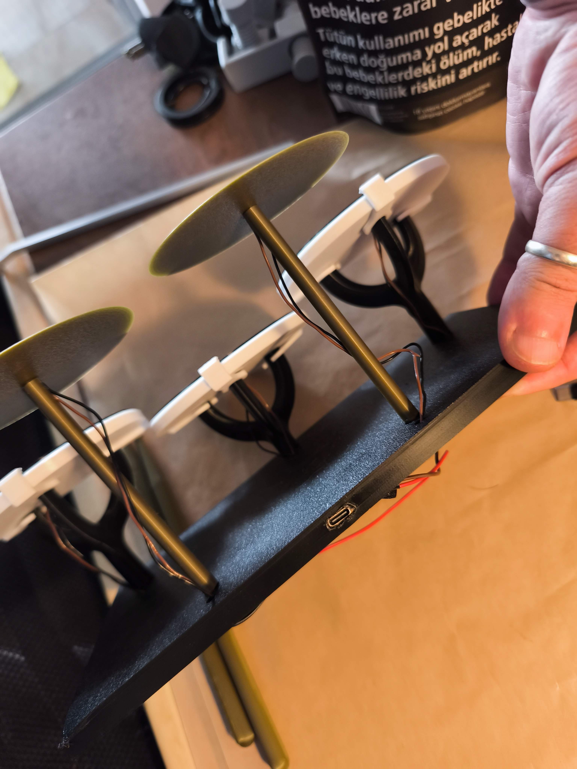
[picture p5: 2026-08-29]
images/controller-port.jpg

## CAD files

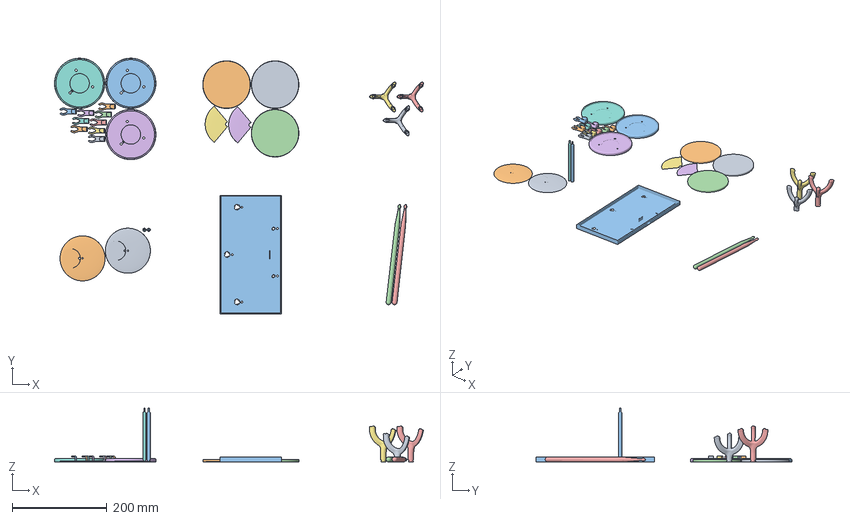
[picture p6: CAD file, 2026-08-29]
3d-models/drumkit.3mf
778.4 x 539.2 x 113.7 mm
drumpad_tpu.stl x 3
Assembly x 2
194.stl x 2
Body206.stl x 2
Body201.stl x 2
drumkit.stl_1 x 3
DrumPad_Leg+5 x 2
DrumPad_Leg_Short
DrumPad Fastener 10 x 9
drumkit.stl

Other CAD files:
3d-models/drumkit2.3mf

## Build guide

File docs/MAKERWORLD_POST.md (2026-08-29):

🥁 3D Printed Bluetooth MIDI Drum Kit!

Built a compact electronic drum kit using ESP32-C3 Super Mini + piezo sensors. All parts are 3D printed!

Features:
• 5 velocity-sensitive pads (kick, snare, hi-hat, tom, cymbal)
• Wireless BLE MIDI - works with GarageBand, BandLab, n-track
• Total cost under $15

The .3mf file has 6 color-coded build plates ready to print.

Full docs + Arduino code: https://github.com/kaanvur/drumkit

Happy to answer questions! 🎵

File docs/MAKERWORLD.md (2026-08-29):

# ESP32-C3 Bluetooth MIDI Drum Kit

A compact, fully 3D-printed electronic drum kit with wireless BLE MIDI connectivity. Built around the ESP32-C3 Super Mini microcontroller, this project turns 5 piezo sensors into a playable MIDI drum set that connects to any Bluetooth-enabled device.

## What's Included

- **5 Drum Pads**: Kick, Snare, Hi-Hat, Tom, Crash Cymbal
- **BLE MIDI**: Wireless Bluetooth connection with low latency (~10ms)
- **Velocity Sensitivity**: Dynamic response based on hit strength
- **3D Printed**: All structural parts are 3D printable (PLA/PLA+)
- **Compact Design**: Desktop-sized, fully portable

## 3D Print Files

The included `.3mf` file contains 6 build plates optimized for multi-color printing:

| Plate | Color | Parts |
|---|---|---|
| 01 | White | Pad frames + clips (3 frames, 12 clips) |
| 02 | Black | Drum pad tops (3 round + 2 cymbal) |
| 03 | Black | Cymbal stands/holders |
| 04 | Green | Cymbal top surfaces + clips |
| 05 | Black | Main base plate |
| 06 | Green | Drumsticks |

**Recommended settings**: PLA/PLA+, 0.2mm layer height, 20-30% infill

## Electronics

- **MCU**: ESP32-C3 Super Mini (USB-C, built-in LED on GPIO8)
- **Sensors**: 5x Piezo sensors (27mm)
- **Resistors**: 5x 1MΩ (pull-down)
- **Wiring**: Simple analog connection - each piezo to a GPIO pin + GND

### GPIO Map

| Pad | GPIO | MIDI Note |
|-----|---|---|
| Kick | GPIO0 | C1 (36) |
| Snare | GPIO1 | D1 (38) |
| Hi-Hat | GPIO2 | F#1 (42) |
| Tom | GPIO3 | C2 (48) |
| Cymbal | GPIO4 | C2 (49) |

## Software

The firmware is written in Arduino IDE using the BLE MIDI protocol. Features include:

- 12-bit ADC reading for precise velocity detection
- Peak detection algorithm with configurable thresholds
- Inverted trigger support (GPIO2)
- MIDI Channel 10 (standard drum channel)
- Automatic BLE advertising on disconnect

## Compatibility

Works with any BLE MIDI-capable device:

| Platform | App | Status |
|---|-----|---|
| macOS | GarageBand, Logic Pro | ✅ |
| iOS | GarageBand, Cubasis 3 | ✅ |
| Android | n-track Studio, Caustic 3 | ✅ |
| Web | BandLab, Soundtrap | ✅ |

## More Information

For full documentation, wiring diagrams, assembly guide, and source code:

**GitHub**: https://github.com/kaanvur/drumkit

## License

CC BY-NC-SA 4.0 - Free for personal use, attribution required, derivative works must use the same license.

## Microcontroller Compatibility

This project uses 5 analog pins (GPIO0-4). You can adapt it to other microcontrollers with more analog pins:

- ESP32-WROOM-32D (18 analog pins → up to 18 pads)
- ESP32-S3 Super Mini (20 analog pins → up to 20 pads)
- Arduino Uno (6 analog pins → up to 6 pads)

Just update `NUM_PADS` and `piezoPins` array in the firmware.

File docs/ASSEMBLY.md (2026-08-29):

# Montaj Rehberi / Assembly Guide

## 🇹🇷 Türkçe

### Adım 1: 3D Baskı

[`drumkit.3mf`](../3d-models/drumkit.3mf) dosyasını Bambu Studio veya PrusaSlicer'da açın.

| Plaka | Renk | Parça | Adet |
|---|---|---|---|
| 01 | Beyaz | Pad çerçeveleri | 3 |
| 01 | Beyaz | Klipsler | 12 |
| 02 | Siyah | Yuvarlak pad üstleri | 3 |
| 02 | Siyah | Zil pad üstleri | 2 |
| 03 | Siyah | Zil ayakları | 2 |
| 04 | Yeşil | Zil üst yüzeyleri | 2 |
| 05 | Siyah | Ana gövde | 1 |
| 06 | Yeşil | Davul çubukları | 2 |

**Baskı Önerileri**:
- Malzeme: PLA veya PLA+
- Katman yüksekliği: 0.2mm
- Doluluk: %20-30
- Destek: Gerekli olabilir (zil ayakları için)

### Adım 2: Piezo Sensörleri Hazırlama

Her piezo sensörü pad'in alt yüzeyine yapıştırılır.

1. Piezo'yu pad'in ortasına yerleştirin
2. Epoksi veya sıcak tutkal ile sabitleyin
3. Kabloları pad'in deliğinden geçirin

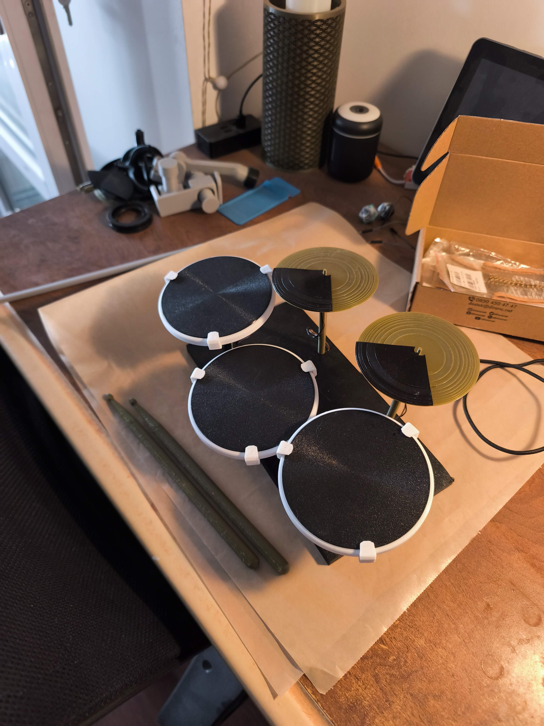
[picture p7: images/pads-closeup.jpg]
Pads closeup


### Adım 3: Kablolama

Her piezo'dan iki kablo çıkar:
- **Kırmızı (+)**: GPIO pinine gidecek
- **Siyah (-)**: GND'ye gidecek

Tüm siyah kabloları birleştirin (ortak GND).

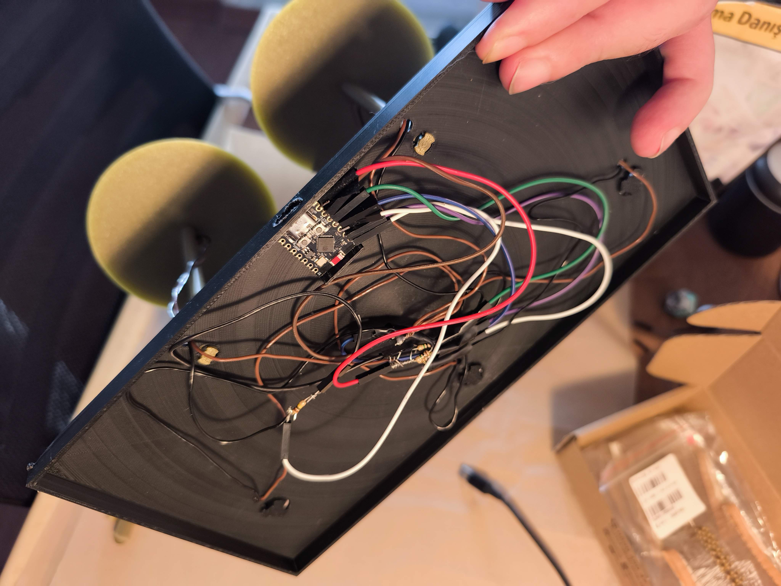
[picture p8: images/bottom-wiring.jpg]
Bottom wiring


### Adım 4: Devre Birleştirme

1. 1MΩ dirençleri her GPIO pini ile GND arasına bağlayın
2. Piezo kablolarını ESP32 pinlerine bağlayın
3. LED bağlantısı gerekmez - ESP32-C3 Super Mini üzerinde yerleşik LED (GPIO8) vardır

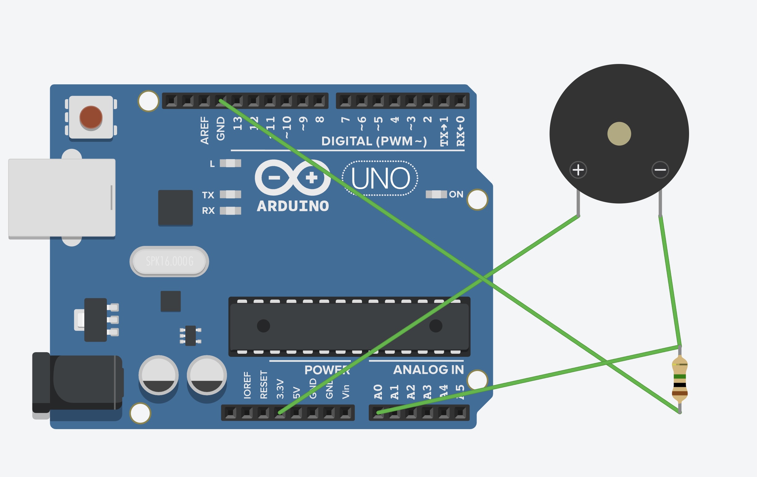
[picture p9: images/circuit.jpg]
Circuit


### Adım 5: Gövdeye Yerleştirme

1. ESP32'yi gövde内部ındaki yuvaya yerleştirin
2. USB-C portu dışarıda kalacak şekilde konumlandırın
3. Kabloları düzenleyin

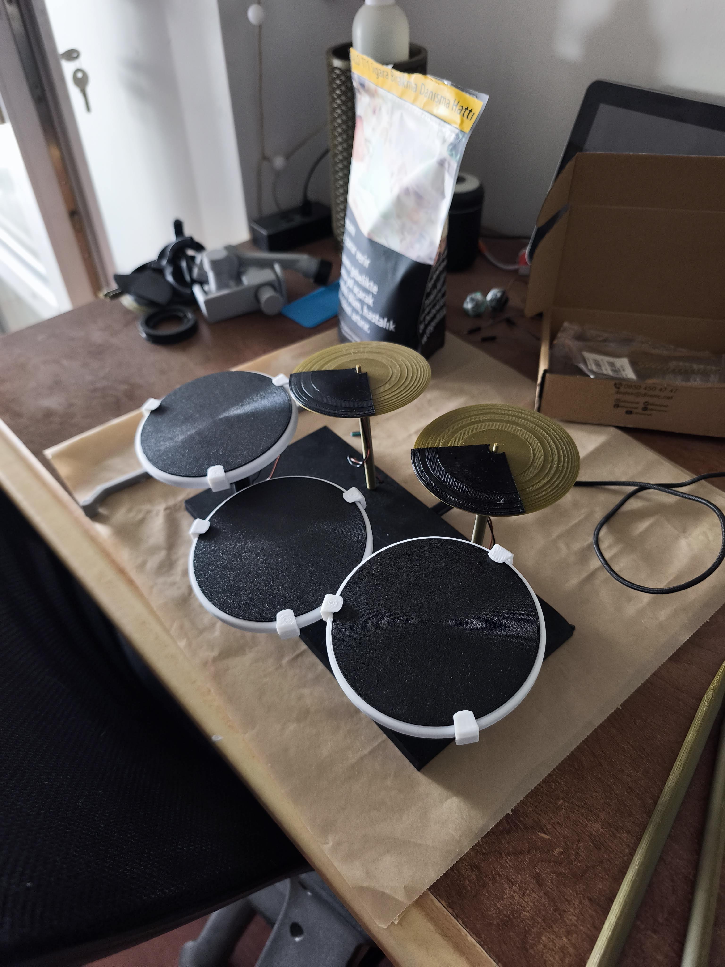
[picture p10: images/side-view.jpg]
Side view


### Adım 6: Pad'leri Montaj Etme

1. Pad çerçevelerini gövde üzerindeki deliklere vidalayın
2. Klipslerle sabitleyin
3. Zil ayaklarını monte edin

Assembled

### Adım 7: Test

1. USB-C ile bilgisayara bağlayın
2. Arduino IDE'den seri monitörü açın
3. Pad'lere vurun, "KICK", "SNARE" etc. yazmalı
4. Bluetooth'u açın, "ESP32-C3-Drum" cihazını arayın

---

## 🇬🇧 English

### Step 1: 3D Printing

Open [`drumkit.3mf`](../3d-models/drumkit.3mf) in Bambu Studio or PrusaSlicer.

| Plate | Color | Part | Qty |
|---|---|---|-----|
| 01 | White | Pad frames | 3 |
| 01 | White | Clips | 12 |
| 02 | Black | Round pad tops | 3 |
| 02 | Black | Cymbal pad tops | 2 |
| 03 | Black | Cymbal stands | 2 |
| 04 | Green | Cymbal top surfaces | 2 |
| 05 | Black | Main base | 1 |
| 06 | Green | Drumsticks | 2 |

**Print Recommendations**:
- Material: PLA or PLA+
- Layer height: 0.2mm
- Infill: 20-30%
- Supports: May be needed (for cymbal stands)

### Step 2: Preparing Piezo Sensors

Each piezo sensor is glued to the bottom surface of a pad.

1. Place piezo in center of pad
2. Secure with epoxy or hot glue
3. Feed wires through pad hole

### Step 3: Wiring

Two wires come from each piezo:
- **Red (+)**: Goes to GPIO pin
- **Black (-)**: Goes to GND

Combine all black wires (common GND).

### Step 4: Circuit Assembly

1. Connect 1MΩ resistors between each GPIO pin and GND
2. Connect piezo wires to ESP32 pins
3. No LED connection needed - ESP32-C3 Super Mini has a built-in LED on GPIO8

### Step 5: Mounting into Base

1. Place ESP32 into its slot inside the base
2. Position so USB-C port is accessible
3. Route and organize wires

### Step 6: Pad Installation

1. Screw pad frames into holes on base
2. Secure with clips
3. Mount cymbal stands

### Step 7: Testing

1. Connect to computer via USB-C
2. Open Serial Monitor in Arduino IDE
3. Hit pads - should print "KICK", "SNARE", etc.
4. Enable Bluetooth - look for "ESP32-C3-Drum" device

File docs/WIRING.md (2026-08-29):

# Bağlantı Rehberi / Wiring Guide

## 🇹🇷 Türkçe

### Analog Pin Gerekliliği

Piezo sensörler **analog pinlere** bağlanır. ADC (Analog-to-Digital Converter) ile okuma yapılır. Her piezo için bir analog pin gereklidir.

| Mikrodenetleyici | Analog Pin Sayısı | Kullanılabilir GPIO'lar |
|---|---|---|
| ESP32-C3 Super Mini | 5 | GPIO0, GPIO1, GPIO2, GPIO3, GPIO4 |
| ESP32-WROOM-32D | 18 | GPIO32-39, GPIO0-5, GPIO34-39 |
| ESP32-S3 Super Mini | 20 | GPIO1-20 |
| Arduino Uno | 6 | A0-A5 |
| Arduino Nano | 8 | A0-A7 |

> **Daha fazla pad için**: ESP32-WROOM-32D gibi daha çok analog pin'e sahip kartlar kullanarak更大鼓组 kurabilirsiniz. Kodda `NUM_PADS` ve `piezoPins` dizisini güncellemeniz yeterlidir.

### Malzeme Listesi

- 1x ESP32-C3 Super Mini (dahili LED: GPIO8)
- 5x Piezo sensör (27mm çap)
- 5x 1MΩ direnç (pull-down)
- Jumper kablolar

### Bağlantı Şeması

Her piezo sensör bir **analog pina** ve **GND**'ye bağlanır. Ayrıca her piezo'ya paralel bir **1MΩ pull-down direnç** eklenir.

```
Piezo Sensör Bağlantısı (her pad için):
                    
    Piezo (+) ────── GPIO Pin ──┐
                               │
    Piezo (-) ────── GND       │
                               │
                    1MΩ direnç ─┘
                   (GPIO ↔ GND)
```

### GPIO Haritası

| Pad | GPIO | MIDI Notu | Eşik Değeri | Trigger Yönü |
|-----|---|---|---|---|
| Kick | GPIO0 | C1 (36) | 200 | Normal (↑) |
| Snare | GPIO1 | D1 (38) | 200 | Normal (↑) |
| Hi-Hat | GPIO2 | F#1 (42) | 60 | **Ters** (↓) |
| Tom | GPIO3 | C2 (48) | 200 | Normal (↑) |
| Cymbal | GPIO4 | C#2 (49) | 200 | Normal (↑) |

> **Not**: GPIO2 ters trigger modundadır. Bos durumda ADC degeri yuksektir (4095), vuruşta düşer.

### Dahili LED

ESP32-C3 Super Mini üzerinde yerleşik bir LED bulunur (GPIO8). Devreye ekstra LED bağlamaya gerek yoktur. Kodda her vuruşta 50ms yanıp söner.

### Direnç Bağlantısı Detayı

Her piezo için pull-down direnci:
- Bir ucu: Piezo (+) / GPIO pinine
- Diğer ucu: GND'ye

Bu direnç, piezo'dan gelen yüksek empedanslı sinyali GND'ye çekerek boş durumda stabil bir okuma sağlar.

### Tam Devre Şeması

```
                    ┌──────────────────────┐
                    │   ESP32-C3 Super Mini │
                    │                      │
    Piezo 1 ────────┤ GPIO0            GND ├──── Piezo (-) hepsi
    Piezo 2 ────────┤ GPIO1                │
    Piezo 3 ────────┤ GPIO2                │
    Piezo 4 ────────┤ GPIO3                │
    Piezo 5 ────────┤ GPIO4                │
                    │                      │
                    │  GPIO8 (Dahili LED)  │
                    │          USB-C ──────┤
                    └──────────────────────┘

    1MΩ dirençler: her GPIO ↔ GND arası
```

### Lehimleme İpuçları

1. Piezo kablolarını uzun tutun (esneklik için)
2. Dirençleri breadboard'da test edin, sonra lehimleyin
3. Tüm GND bağlantılarını birleştirin (ortak toprak)
4. Short devre kontrolü yapın

---

## 🇬🇧 English

### Analog Pin Requirement

Piezo sensors connect to **analog pins**. They are read using ADC (Analog-to-Digital Converter). Each piezo requires one analog pin.

| Microcontroller | Analog Pin Count | Available GPIOs |
|---|---|---|
| ESP32-C3 Super Mini | 5 | GPIO0, GPIO1, GPIO2, GPIO3, GPIO4 |
| ESP32-WROOM-32D | 18 | GPIO32-39, GPIO0-5, GPIO34-39 |
| ESP32-S3 Super Mini | 20 | GPIO1-20 |
| Arduino Uno | 6 | A0-A5 |
| Arduino Nano | 8 | A0-A7 |

> **For more pads**: Use microcontrollers with more analog pins like ESP32-WROOM-32D to build larger drum kits. Just update `NUM_PADS` and `piezoPins` array in the code.

### Components

- 1x ESP32-C3 Super Mini (built-in LED: GPIO8)
- 5x Piezo sensors (27mm diameter)
- 5x 1MΩ resistors (pull-down)
- Jumper wires

### Wiring Diagram

Each piezo sensor connects to an **analog pin** and **GND**. A **1MΩ pull-down resistor** is placed in parallel with each piezo.

```
Piezo Sensor Connection (for each pad):

    Piezo (+) ────── GPIO Pin ──┐
                               │
    Piezo (-) ────── GND       │
                               │
                    1MΩ resistor ─┘
                   (GPIO ↔ GND)
```

### GPIO Map

| Pad | GPIO | MIDI Note | Threshold | Trigger Direction |
|-----|---|---|---|---|
| Kick | GPIO0 | C1 (36) | 200 | Normal (↑) |
| Snare | GPIO1 | D1 (38) | 200 | Normal (↑) |
| Hi-Hat | GPIO2 | F#1 (42) | 60 | **Inverted** (↓) |
| Tom | GPIO3 | C2 (48) | 200 | Normal (↑) |
| Cymbal | GPIO4 | C#2 (49) | 200 | Normal (↑) |

> **Note**: GPIO2 is in inverted trigger mode. Idle ADC value is high (4095), drops on hit.

### Built-in LED

ESP32-C3 Super Mini has a built-in LED on GPIO8. No external LED connection is needed. In the code, it flashes for 50ms on each hit.

### Full Circuit

```
                    ┌──────────────────────┐
                    │   ESP32-C3 Super Mini │
                    │                      │
    Piezo 1 ────────┤ GPIO0            GND ├──── Piezo (-) all
    Piezo 2 ────────┤ GPIO1                │
    Piezo 3 ────────┤ GPIO2                │
    Piezo 4 ────────┤ GPIO3                │
    Piezo 5 ────────┤ GPIO4                │
                    │                      │
                    │  GPIO8 (Built-in LED)│
                    │          USB-C ──────┤
                    └──────────────────────┘

    1MΩ resistors: between each GPIO ↔ GND
```

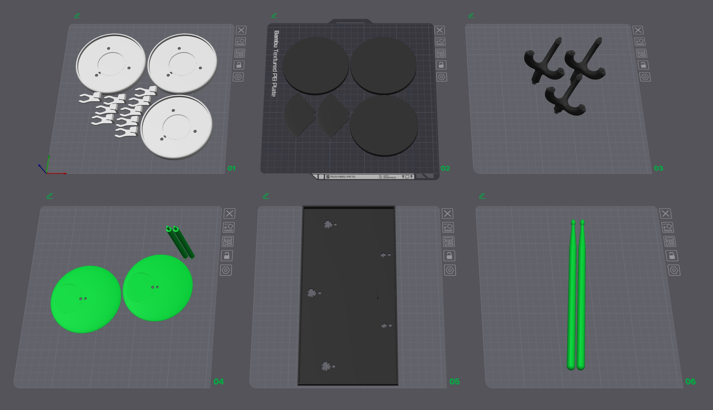
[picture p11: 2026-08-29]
images/print-plates.jpg

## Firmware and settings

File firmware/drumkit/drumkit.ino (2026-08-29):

#include <BLEDevice.h>
#include <BLEUtils.h>
#include <BLEServer.h>
#include <BLE2902.h>
#include <Arduino.h>
#include <math.h>

// =====================================================
// BLE MIDI UUID
// =====================================================

#define SERVICE_UUID        "03b80e5a-ede8-4b33-a751-6ce34ec4c700"
#define CHARACTERISTIC_UUID "7772e5db-3868-4112-a1a9-f2669d106bf3"

BLECharacteristic *pCharacteristic;
bool deviceConnected = false;


// =====================================================
// PAD SAYISI
// =====================================================

#define NUM_PADS 5


// =====================================================
// PAD PINLERI
// =====================================================

const int piezoPins[NUM_PADS] = {
  0,  // GPIO0 - Kick
  1,  // GPIO1 - Snare
  2,  // GPIO2 - Tom (TERS OKUMA)
  3,  // GPIO3 - Hi-Hat
  4   // GPIO4 - Cymbal
};


// =====================================================
// TRIGGER YONU
//
// true  = normal: vurunca ADC degeri yukselir
// false = ters:   vurunca ADC degeri duser
// =====================================================

const bool triggerPositive[NUM_PADS] = {
  true,   // GPIO0
  true,   // GPIO1
  false,  // GPIO2 -> Bos durumda 4095, vurunca asagi duser
  true,   // GPIO3
  true    // GPIO4
};


// =====================================================
// MIDI NOTALARI
// =====================================================

const uint8_t midiNotes[NUM_PADS] = {
  36, // GPIO0 - Kick
  38, // GPIO1 - Snare
  42, // GPIO2 - Closed Hi-Hat
  48, // GPIO3 - Tom
  49  // GPIO4 - Crash Cymbal
};


// =====================================================
// PAD ISIMLERI
// =====================================================

const char* padNames[NUM_PADS] = {
  "KICK",
  "SNARE",
  "HI-HAT",
  "TOM",
  "CYMBAL"
};


// =====================================================
// DRUM TRIGGER AYARLARI
// =====================================================

const int thresholds[NUM_PADS] = {
  200, // GPIO0
  200, // GPIO1
  60, // GPIO2
  200, // GPIO3
  200  // GPIO4
};

const int resetThreshold = 50;

const unsigned long peakWindow = 8;
const unsigned long maskTime = 70;
const unsigned long noteDuration = 20;


// =====================================================
// LED
// =====================================================

const int ledPin = 8;
const unsigned long ledDuration = 50;

bool ledActive = false;
unsigned long ledStartTime = 0;


// =====================================================
// TRIGGER STATE
// =====================================================

enum TriggerState {
  READY,
  CAPTURING_PEAK,
  WAIT_FOR_RESET
};

TriggerState triggerStates[NUM_PADS];

int peakValues[NUM_PADS];

unsigned long triggerStartTimes[NUM_PADS];

unsigned long lastTriggerTimes[NUM_PADS];

bool notesOn[NUM_PADS];

unsigned long noteOnTimes[NUM_PADS];


// =====================================================
// BLE CALLBACK
// =====================================================

class MyServerCallbacks : public BLEServerCallbacks {

  void onConnect(BLEServer* pServer) {
    deviceConnected = true;
    Serial.println("Bluetooth cihazi baglandi!");
  }

  void onDisconnect(BLEServer* pServer) {
    deviceConnected = false;

    Serial.println("Bluetooth baglantisi koptu.");

    delay(100);

    BLEDevice::startAdvertising();
  }
};


// =====================================================
// LED FLASH
// =====================================================

void flashLED() {
  digitalWrite(ledPin, HIGH);

  ledActive = true;

  ledStartTime = millis();
}


// =====================================================
// MIDI NOTE ON
// =====================================================

void sendMidiNoteOn(int pad, uint8_t velocity) {

  // BLE bagli degilse trigger ve LED yine calisir
  if (!deviceConnected) {
    return;
  }

  uint8_t midiPacket[] = {
    0x80,
    0x80,
    0x99, // MIDI Channel 10 - Drum
    midiNotes[pad],
    velocity
  };

  pCharacteristic->setValue(
    midiPacket,
    sizeof(midiPacket)
  );

  pCharacteristic->notify();

  notesOn[pad] = true;
  noteOnTimes[pad] = millis();
}


// =====================================================
// MIDI NOTE OFF
// =====================================================

void sendMidiNoteOff(int pad) {

  if (!deviceConnected) {
    notesOn[pad] = false;
    return;
  }

  uint8_t midiPacket[] = {
    0x80,
    0x80,
    0x89,
    midiNotes[pad],
    0
  };

  pCharacteristic->setValue(
    midiPacket,
    sizeof(midiPacket)
  );

  pCharacteristic->notify();

  notesOn[pad] = false;
}


// =====================================================
// VELOCITY HESAPLAMA
// =====================================================

uint8_t calculateVelocity(
  int peak,
  int threshold
) {

  const int maxPeak = 3500;

  peak = constrain(
    peak,
    threshold,
    maxPeak
  );

  float normalized =
    (float)(peak - threshold) /
    (float)(maxPeak - threshold);

  normalized = constrain(
    normalized,
    0.0,
    1.0
  );

  // Daha hassas dusuk ve orta vuruslar
  normalized = sqrt(normalized);

  int velocity =
    1 + (normalized * 126);

  velocity = constrain(
    velocity,
    1,
    127
  );

  return velocity;
}


// =====================================================
// SETUP
// =====================================================

void setup() {

  Serial.begin(115200);


  // LED

  pinMode(ledPin, OUTPUT);

  digitalWrite(ledPin, LOW);


  // ADC

  analogReadResolution(12);


  // PAD STATE INITIALIZATION

  for (int i = 0; i < NUM_PADS; i++) {

    triggerStates[i] = READY;

    peakValues[i] = 0;

    triggerStartTimes[i] = 0;

    lastTriggerTimes[i] = 0;

    notesOn[i] = false;

    noteOnTimes[i] = 0;
  }


  // BLE MIDI

  BLEDevice::init("ESP32-C3-Drum");

  BLEServer *pServer =
    BLEDevice::createServer();

  pServer->setCallbacks(
    new MyServerCallbacks()
  );

  BLEService *pService =
    pServer->createService(
      SERVICE_UUID
    );

  pCharacteristic =
    pService->createCharacteristic(

      CHARACTERISTIC_UUID,

      BLECharacteristic::PROPERTY_READ |
      BLECharacteristic::PROPERTY_NOTIFY |
      BLECharacteristic::PROPERTY_WRITE_NR

    );

  pCharacteristic->addDescriptor(
    new BLE2902()
  );

  pService->start();

  BLEAdvertising *pAdvertising =
    BLEDevice::getAdvertising();

  pAdvertising->addServiceUUID(
    SERVICE_UUID
  );

  pAdvertising->setScanResponse(true);

  pAdvertising->start();


  Serial.println();
  Serial.println("================================");
  Serial.println("ESP32-C3 5 PAD DRUM HAZIR");
  Serial.println("GPIO2 TERS TRIGGER MODUNDA");
  Serial.println("================================");
}


// =====================================================
// LOOP
// =====================================================

void loop() {

  unsigned long now = millis();


  // ===================================================
  // LED TIMER
  // ===================================================

  if (
    ledActive &&
    now - ledStartTime >= ledDuration
  ) {

    digitalWrite(ledPin, LOW);

    ledActive = false;
  }


  // ===================================================
  // HER PAD'I KONTROL ET
  // ===================================================

  for (int i = 0; i < NUM_PADS; i++) {


    // ADC OKU

    int sensorValue =
      analogRead(
        piezoPins[i]
      );


    // =================================================
    // TRIGGER DEGERINI NORMALIZE ET
    //
    // Normal pinler:
    //   Bos -> dusuk
    //   Vurus -> yuksek
    //
    // GPIO2:
    //   Bos -> 4095
    //   Vurus -> asagi duser
    // =================================================

    int triggerValue;

    if (triggerPositive[i]) {

      triggerValue = sensorValue;

    } else {

      // GPIO2 icin ters trigger
      triggerValue = 4095 - sensorValue;
    }


    // =================================================
    // READY
    // =================================================

    if (triggerStates[i] == READY) {

      if (
        triggerValue > thresholds[i] &&
        now - lastTriggerTimes[i] >= maskTime
      ) {

        peakValues[i] = triggerValue;

        triggerStartTimes[i] = now;

        triggerStates[i] = CAPTURING_PEAK;
      }
    }


    // =================================================
    // CAPTURING PEAK
    // =================================================

    else if (
      triggerStates[i] == CAPTURING_PEAK
    ) {

      // Peak degerini bul

      if (
        triggerValue > peakValues[i]
      ) {

        peakValues[i] = triggerValue;
      }


      // Peak window tamamlandi

      if (
        now - triggerStartTimes[i] >= peakWindow
      ) {

        uint8_t velocity =
          calculateVelocity(
            peakValues[i],
            thresholds[i]
          );


        // DEBUG

        Serial.print(padNames[i]);

        Serial.print(" | ADC: ");

        Serial.print(sensorValue);

        Serial.print(" | Trigger: ");

        Serial.print(triggerValue);

        Serial.print(" | Peak: ");

        Serial.print(peakValues[i]);

        Serial.print(" | Velocity: ");

        Serial.println(velocity);


        // LED her zaman calisir

        flashLED();


        // MIDI

        sendMidiNoteOn(
          i,
          velocity
        );


        lastTriggerTimes[i] = now;

        triggerStates[i] = WAIT_FOR_RESET;
      }
    }


    // =================================================
    // WAIT FOR RESET
    // =================================================

    else if (
      triggerStates[i] == WAIT_FOR_RESET
    ) {

      if (
        triggerValue < resetThreshold &&
        now - lastTriggerTimes[i] >= maskTime
      ) {

        triggerStates[i] = READY;
      }
    }


    // =================================================
    // MIDI NOTE OFF
    // =================================================

    if (
      notesOn[i] &&
      now - noteOnTimes[i] >= noteDuration
    ) {

      sendMidiNoteOff(i);
    }
  }
}

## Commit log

2026-08-29 fix: LED referanslarını düzelt (dahili LED), lisansı CC BY-NC-SA 4.0 olarak değiştir, online platformları ekle, analog pin gerekliliğini belirt
    - README: Malzeme listesinden harici LED kaldırıldı, ESP32-C3 dahili LED (GPIO8) olarak belirtildi
    - WIRING: LED bağlantı şeması kaldırıldı, dahili LED bölümü eklendi
    - ASSEMBLY: LED bağlantı adımı kaldırıldı
    - LICENSE: MIT → CC BY-NC-SA 4.0 olarak değiştirildi
    - BLUETOOTH: BandLab, Soundtrap, Web MIDI API eklendi
    - README: Analog pin gerekliliği ve alternatif kartlar (ESP32-WROOM-32D vb.) eklendi
2026-08-29 update: generic profile
    [drumkit.3mf]
2026-08-29 update: print file
    [drumkit.3mf]
2026-08-29 3D model dosyalarını güncelle
    [drumkit.3mf, drumkit2.3mf]
